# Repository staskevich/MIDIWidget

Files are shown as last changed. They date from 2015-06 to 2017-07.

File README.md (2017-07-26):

MIDIWidget

copyright 2015-2017 John Staskevich

john@codeandcopper.com

This work is licensed under a Creative Commons Attribution 4.0 International License.
http://creativecommons.org/licenses/by/4.0/

HARDWARE:

Eagle 6 board and schematic are in the pcb/ folder. There is also a design for a "programming cradle" that mates the test points on the MIDIWidget with a AVR programmer for ISP.

A public CircuitHub project is available for on-demand manufacturing:
https://circuithub.com/projects/CodeandCopper1/MIDIWidget

FIRMWARE:

See README.txt in Firmware/ and Bootloader/ folders.

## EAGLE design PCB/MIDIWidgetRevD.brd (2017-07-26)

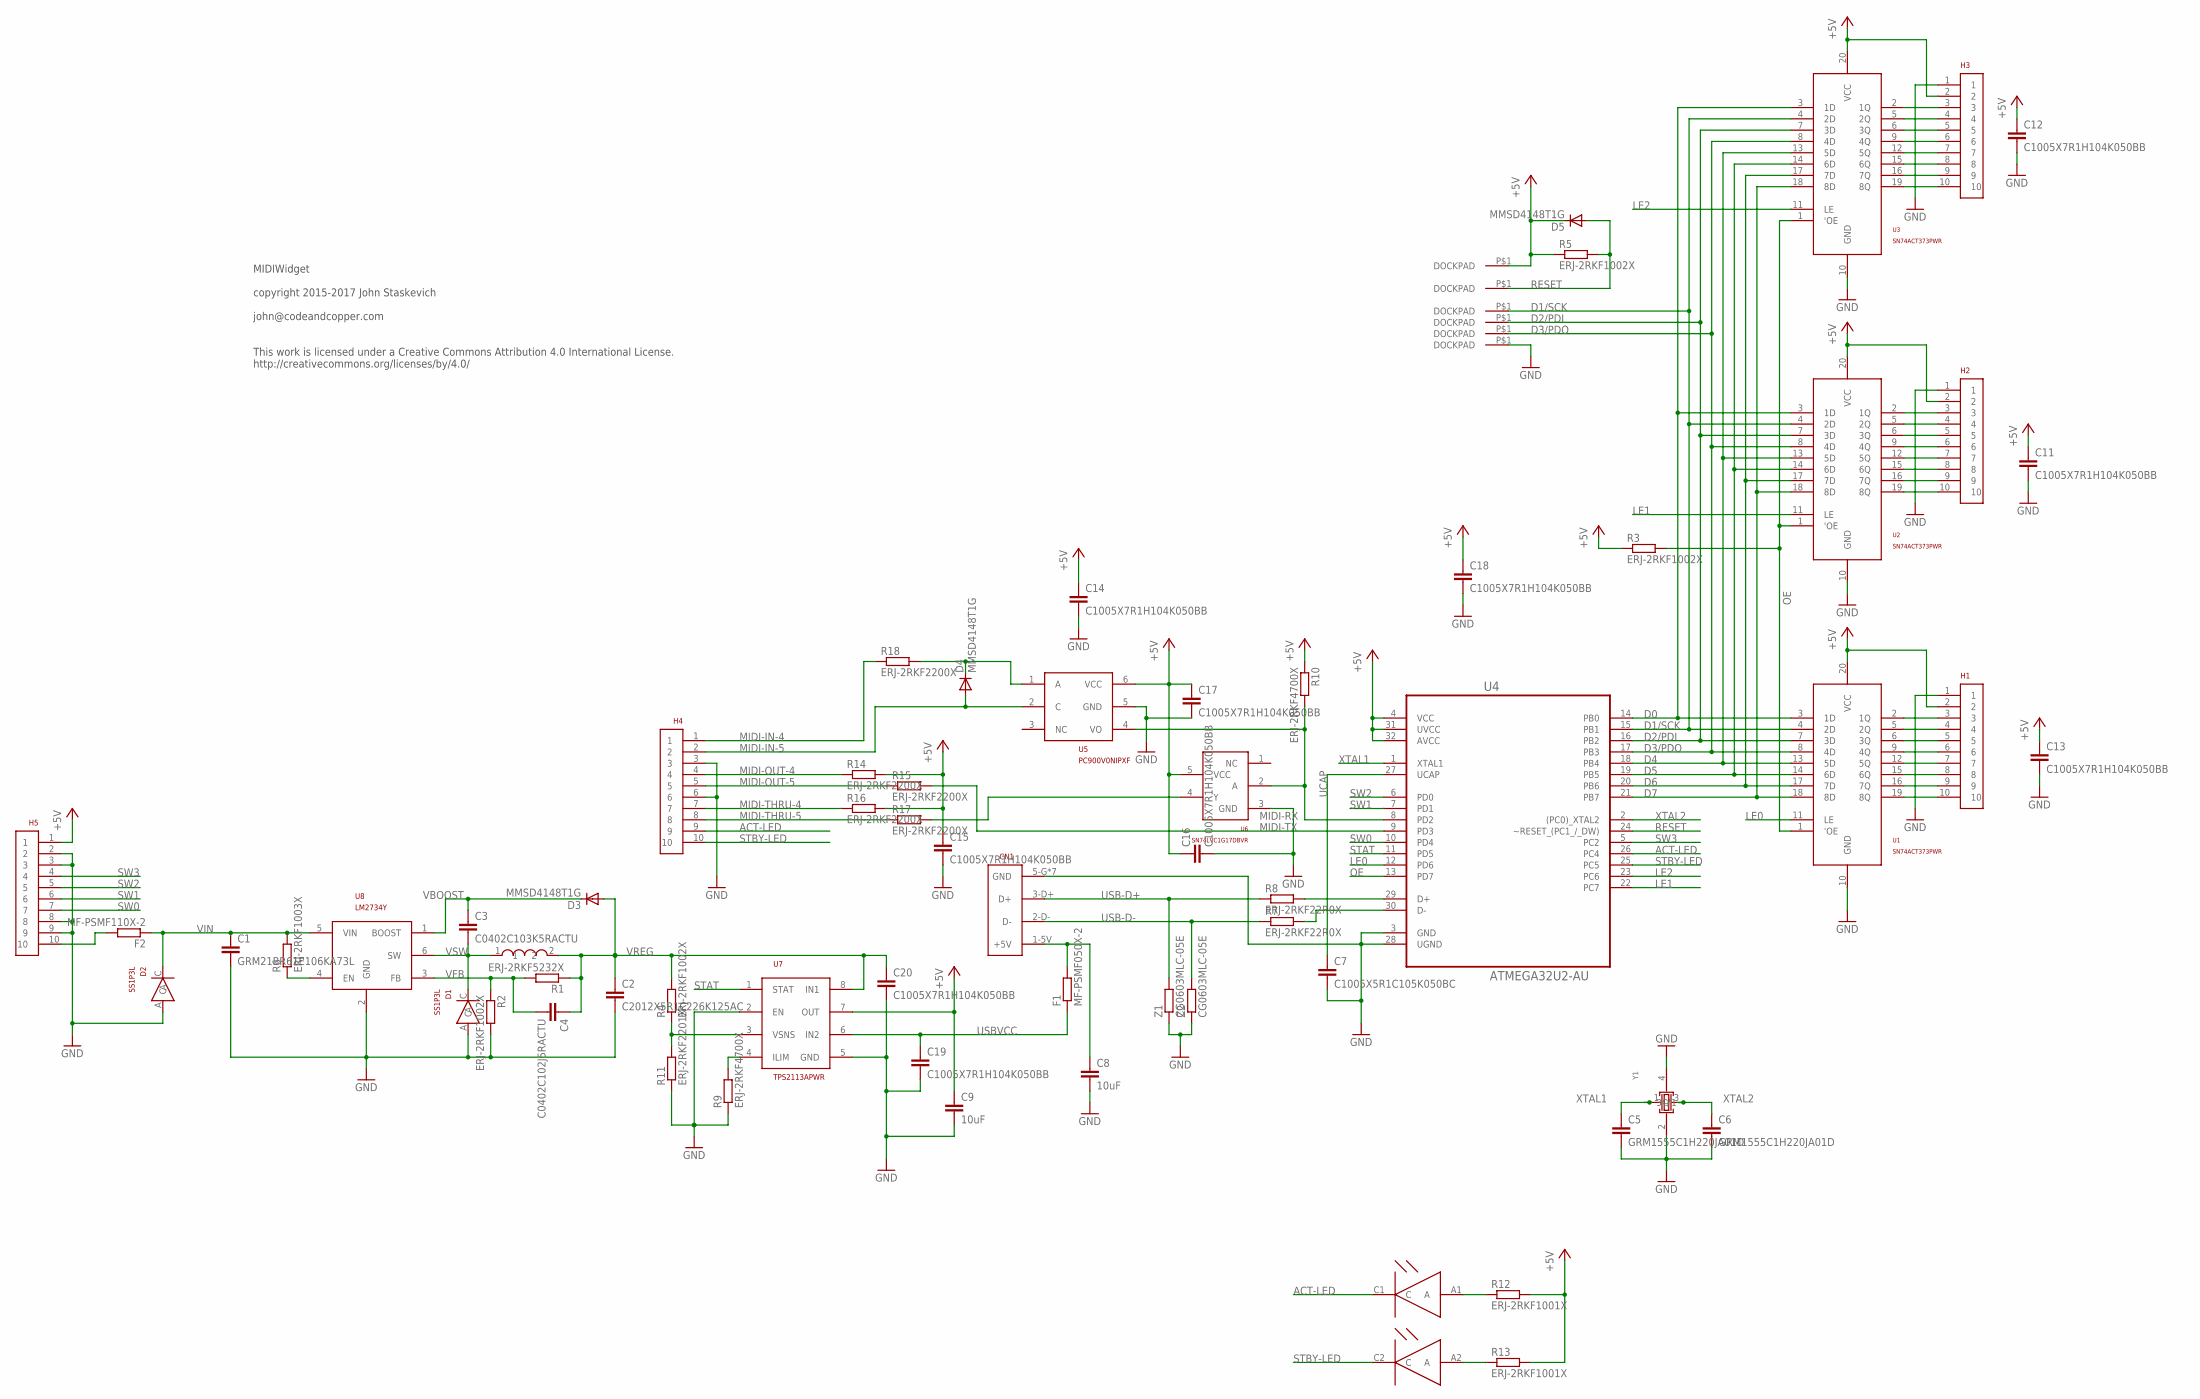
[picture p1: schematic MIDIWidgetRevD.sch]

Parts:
C1: GRM21BR61E106KA73L; C0805
C2: C2012X5R1C226K125AC; C0805
C3: C0402C103K5RACTU; C0402
C4: C0402C102J5RACTU; C0402
C5, C6: GRM1555C1H220JA01D; C0402
C7: C1005X5R1C105K050BC; C0402
C8, C9: 10uF; C0805
C11, C12, C13, C14, C15, C16, C17, C18, C19, C20: C1005X7R1H104K050BB; C0402
CN1: 10118192-0001LF; USB-MICRO-B
D1, D2: SS1P3L; DO-220AA(SMP)
D3, D4, D5: MMSD4148T1G; SOD123
DOCK-GND: DOCKPAD; DOCKPAD-ROUND-2.0MM
DOCK-PDI: DOCKPAD; DOCKPAD-ROUND-2.0MM
DOCK-PDO: DOCKPAD; DOCKPAD-ROUND-2.0MM
DOCK-RESET: DOCKPAD; DOCKPAD-ROUND-2.0MM
DOCK-SCK: DOCKPAD; DOCKPAD-ROUND-2.0MM
DOCK-VCC: DOCKPAD; DOCKPAD-ROUND-2.0MM
F1: MF-PSMF050X-2; R0805
F2: MF-PSMF110X-2; R0805
H1, H2, H3, H4, H5: TERMINAL-BLOCK-10POS; TB-2-54-10POS
L1: SLF7055T-220M1R7-3PF; SLF7055
LED: HSMF-C155; LUMEX-1210-DUAL-LED
R1: ERJ-2RKF5232X; R0402
R2, R3, R4, R5: ERJ-2RKF1002X; R0402
R6: ERJ-2RKF1003X; R0402
R7, R8: ERJ-2RKF22R0X; R0402
R9, R10: ERJ-2RKF4700X; R0402
R11: ERJ-2RKF2201X; R0402
R12, R13: ERJ-2RKF1001X; R0402
R14, R15, R16, R17, R18: ERJ-2RKF2200X; R0402
U1, U2, U3: SN74ACT373PWR; TSSOP-20
U4: ATMEGA32U2-AU; QFP80P900X900X120-32N
U5: PC900V0NIPXF; SMT-6
U6: SN74LVC1G17DBVR; SOT23-5-GOOD
U7: TPS2113APWR; TSSOP-8-NAKED
U8: LM2734Y; TSOT-6
Y1: 403C35E16M00000; CRYSTAL-32-25MM
Z1, Z2: CG0603MLC-05E; R0603

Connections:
+5V: C9.1, C11.1, C12.1, C13.1, C14.1, C15.1, C16.1, C17.1, C18.1, D5.C, DOCK-VCC.P$1, H1.2, H2.2, H3.2, H5.1, R3.1, R5.1, R10.1, R12.2, R13.2, R14.2, R16.2, U1.20 (VCC), U2.20 (VCC), U3.20 (VCC), U4.4 (VCC), U4.31 (UVCC), U4.32 (AVCC), U5.6 (VCC), U6.5 (VCC), U7.7 (OUT)
ACT-LED: H4.9, LED.C1 (C), U4.26 (PC4)
D0: U1.3 (1D), U2.3 (1D), U3.3 (1D), U4.14 (PB0)
D1/SCK: DOCK-SCK.P$1, U1.4 (2D), U2.4 (2D), U3.4 (2D), U4.15 (PB1)
D2/PDI: DOCK-PDI.P$1, U1.7 (3D), U2.7 (3D), U3.7 (3D), U4.16 (PB2)
D3/PDO: DOCK-PDO.P$1, U1.8 (4D), U2.8 (4D), U3.8 (4D), U4.17 (PB3)
D4: U1.13 (5D), U2.13 (5D), U3.13 (5D), U4.18 (PB4)
D5: U1.14 (6D), U2.14 (6D), U3.14 (6D), U4.19 (PB5)
D6: U1.17 (7D), U2.17 (7D), U3.17 (7D), U4.20 (PB6)
D7: U1.18 (8D), U2.18 (8D), U3.18 (8D), U4.21 (PB7)
EN: R6.1, U8.4 (EN)
GND: C1.2, C2.2, C5.2, C6.2, C7.2, C8.2, C9.2, C11.2, C12.2, C13.2, C14.2, C15.2, C16.2, C17.2, C18.2, C19.2, C20.2, CN1.5-G (GND), CN1.P$1 (GND), CN1.P$2 (GND), CN1.P$3 (GND), CN1.P$4 (GND), CN1.P$10 (GND), CN1.P$11 (GND), D1.A, D2.A, DOCK-GND.P$1, H1.1, H2.1, H3.1, H4.3, H4.6, H5.2, H5.3, H5.8, H5.9, R2.2, R9.1, R11.1, U1.10 (GND), U2.10 (GND), U3.10 (GND), U4.3 (GND), U4.28 (UGND), U5.5 (GND), U6.3 (GND), U7.2 (EN), U7.5 (GND), U8.2 (GND), Y1.2, Y1.4, Z1.1, Z2.1
ILIM: R9.2, U7.4 (ILIM)
LE0: U1.11 (LE), U4.12 (PD6)
LE1: U2.11 (LE), U4.22 (PC7)
LE2: U3.11 (LE), U4.23 (PC6)
MIDI-IN-4: H4.1, R18.1
MIDI-IN-5: D4.A, H4.2, U5.2 (C)
MIDI-OUT-4: H4.4, R14.1
MIDI-OUT-5: H4.5, R15.1
MIDI-RX: R10.2, U4.8 (PD2), U5.4 (VO), U6.2 (A)
MIDI-THRU-4: H4.7, R16.1
MIDI-THRU-5: H4.8, R17.1
MIDI-TX: R15.2, U4.9 (PD3)
unnamed: H1.10, U1.19 (8Q)
unnamed: H1.9, U1.16 (7Q)
unnamed: H1.8, U1.15 (6Q)
unnamed: H1.7, U1.12 (5Q)
unnamed: H1.6, U1.9 (4Q)
unnamed: H1.5, U1.6 (3Q)
unnamed: H1.4, U1.5 (2Q)
unnamed: H1.3, U1.2 (1Q)
unnamed: H2.3, U2.2 (1Q)
unnamed: H2.4, U2.5 (2Q)
unnamed: H2.5, U2.6 (3Q)
unnamed: H2.6, U2.9 (4Q)
unnamed: H2.7, U2.12 (5Q)
unnamed: H2.8, U2.15 (6Q)
unnamed: H2.9, U2.16 (7Q)
unnamed: H2.10, U2.19 (8Q)
unnamed: H3.9, U3.16 (7Q)
unnamed: H3.10, U3.19 (8Q)
unnamed: H3.8, U3.15 (6Q)
unnamed: H3.7, U3.12 (5Q)
unnamed: H3.6, U3.9 (4Q)
unnamed: H3.5, U3.6 (3Q)
unnamed: H3.4, U3.5 (2Q)
unnamed: H3.3, U3.2 (1Q)
unnamed: D4.C, R18.2, U5.1 (A)
unnamed: LED.A1 (A), R12.1
unnamed: LED.A2 (A), R13.1
unnamed: F2.2, H5.10
unnamed: C8.1, CN1.1-5V (+5V), F1.2
unnamed: R17.2, U6.4 (Y)
OE: R3.2, U1.1 ('OE), U2.1 ('OE), U3.1 ('OE), U4.13 (PD7)
RESET: D5.A, DOCK-RESET.P$1, R5.2, U4.24 (~RESET_(PC1_/_DW))
STAT: U4.11 (PD5), U7.1 (STAT)
STBY-LED: H4.10, LED.C2 (C), U4.25 (PC5)
SW0: H5.7, U4.10 (PD4)
SW1: H5.6, U4.7 (PD1)
SW2: H5.5, U4.6 (PD0)
SW3: H5.4, U4.5 (PC2)
UCAP: C7.1, U4.27 (UCAP)
USB-D+: CN1.3-D+ (D+), R8.1, Z1.2
USB-D+R: R8.2, U4.29 (D+)
USB-D-: CN1.2-D- (D-), R7.1, Z2.2
USB-D-R: R7.2, U4.30 (D-)
USBVCC: C19.1, F1.1, U7.6 (IN2)
VBOOST: C3.1, D3.C, U8.1 (BOOST)
VFB: C4.2, R1.2, R2.1, U8.3 (FB)
VIN: C1.1, D2.C, F2.1, R6.2, U8.5 (VIN)
VREG: C2.1, C4.1, C20.1, D3.A, L1.2, R1.1, R4.2, U7.8 (IN1)
VSNS: R4.1, R11.2, U7.3 (VSNS)
VSW: C3.2, D1.C, L1.1, U8.6 (SW)
XTAL1: C5.1, U4.1 (XTAL1), Y1.1
XTAL2: C6.1, U4.2 ((PC0)_XTAL2), Y1.3

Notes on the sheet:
MIDIWidget copyright 2015-2017 John Staskevich john@codeandcopper.com This work is licensed under a Creative Commons Attribution 4.0 International License. http://creativecommons.org/licenses/by/4.0/

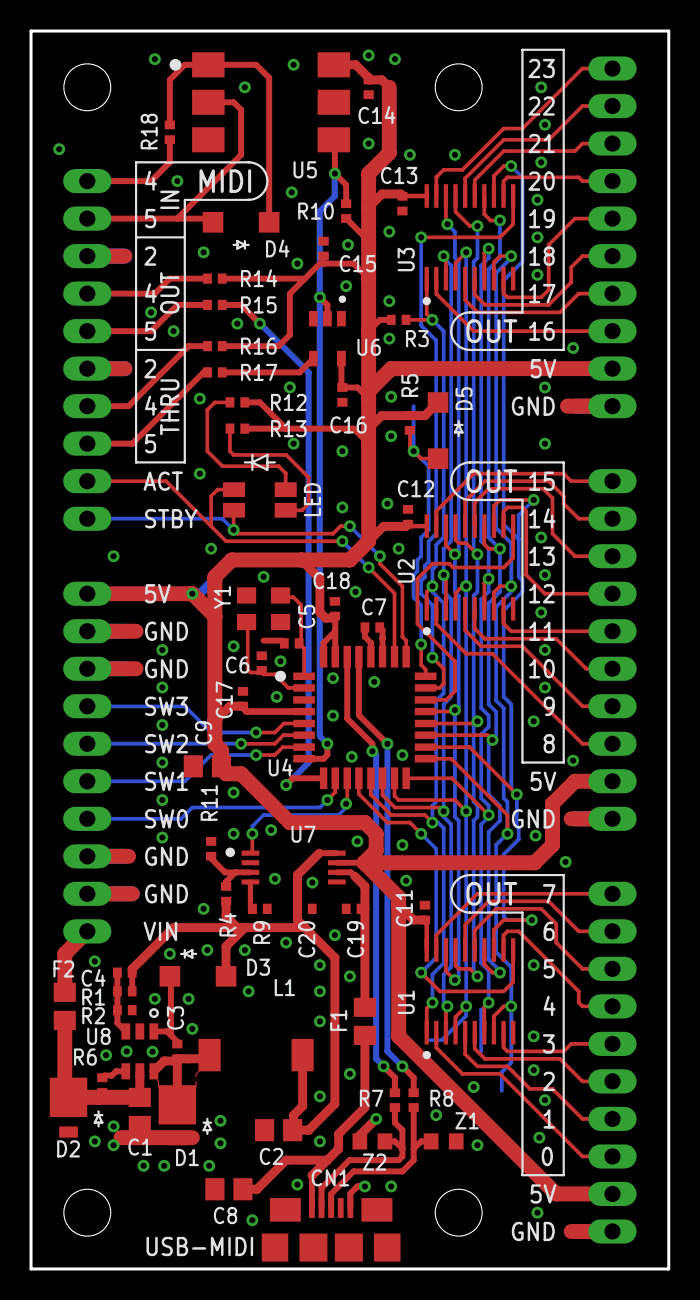
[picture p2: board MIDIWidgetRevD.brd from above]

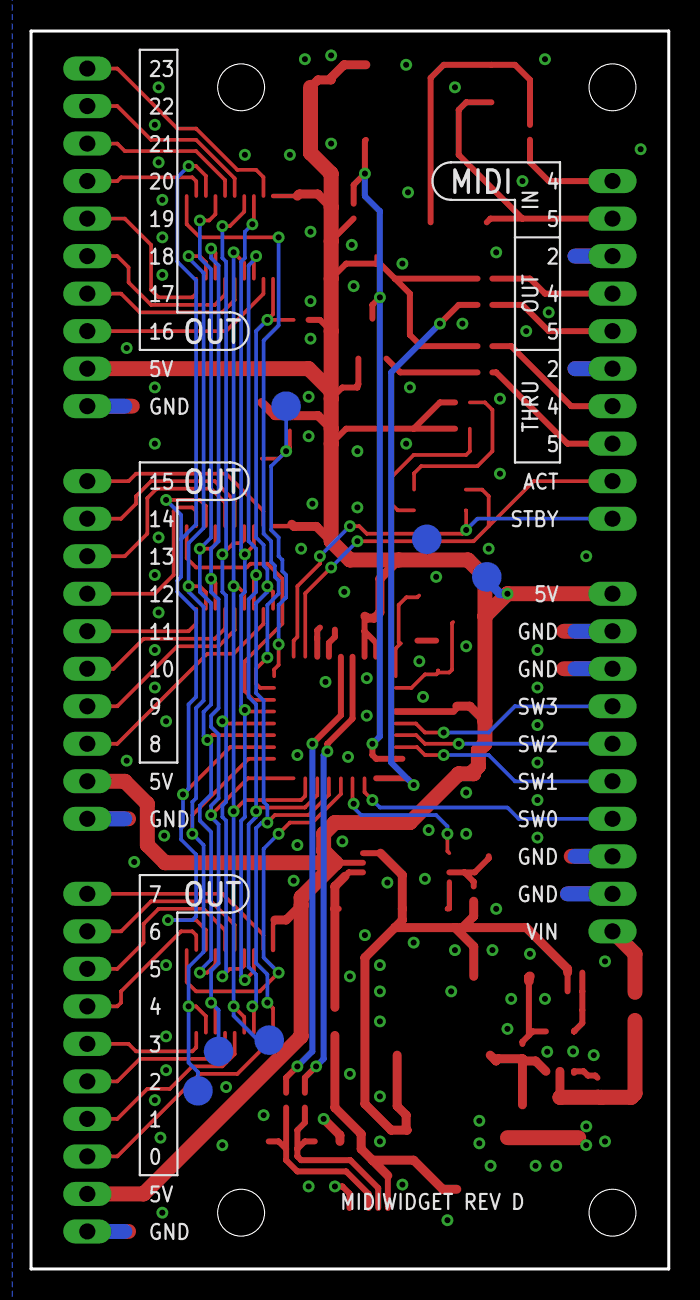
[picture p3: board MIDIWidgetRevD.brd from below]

Board: 2 copper layers, 43.2 x 83.8 mm, 69 parts (6 on the bottom side), 76 nets.

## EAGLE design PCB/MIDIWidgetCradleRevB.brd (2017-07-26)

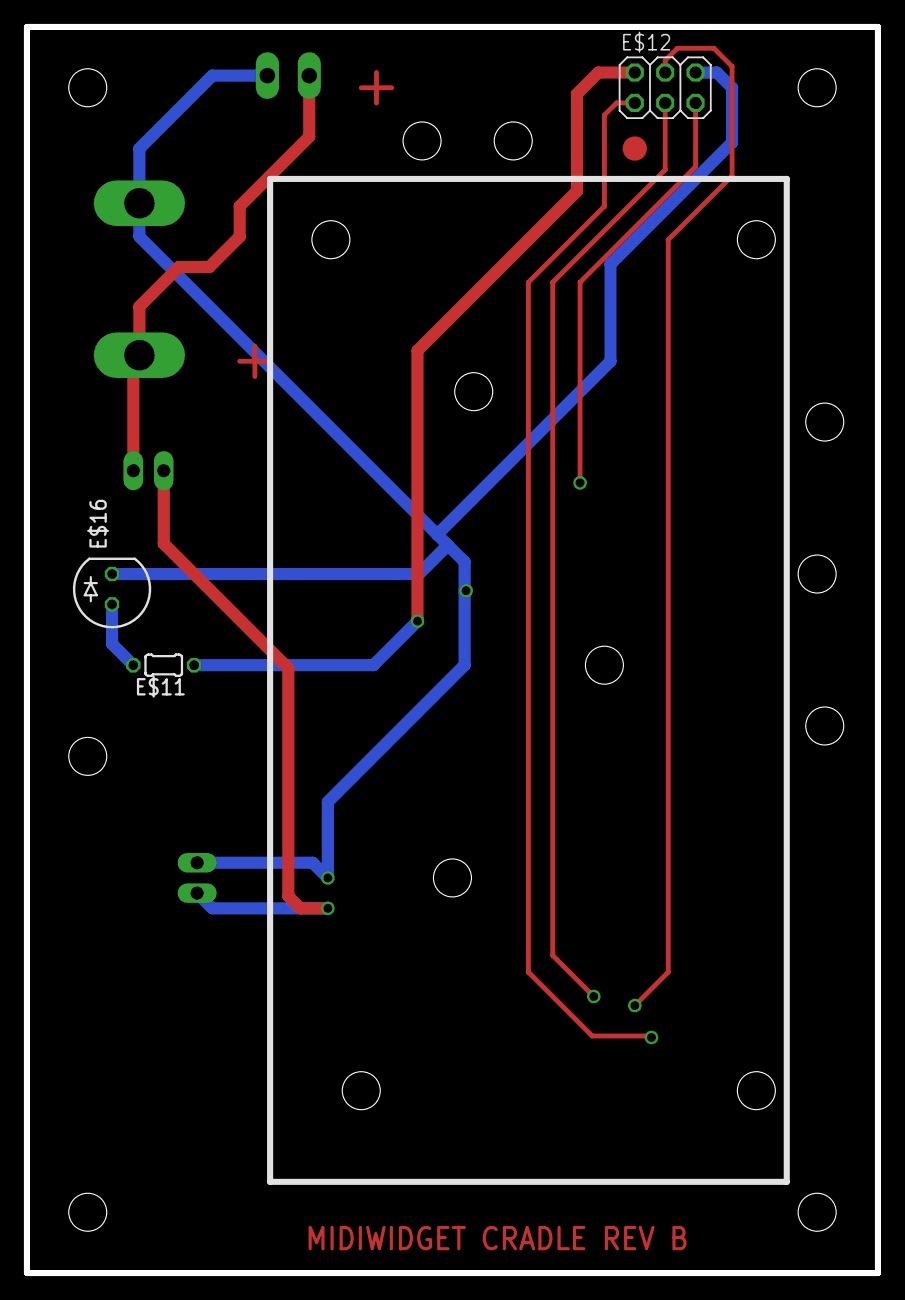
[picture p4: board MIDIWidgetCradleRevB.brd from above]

Board: 2 copper layers, 71.1 x 104.1 mm, 15 parts (0 on the bottom side), 9 nets.

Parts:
E$1: STUD9V
E$2: TERMINAL-BLOCK-3-5-2POS
E$3, E$4, E$5, E$6, E$7, E$8, E$9, E$10: SPRING-CONTACT-025
E$11: 0204/5
E$12: 2X03
E$13, E$15: TB-2-54-2POS
E$16: LED5MM

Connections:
GND: E$1.P$2, E$2.P$1, E$4.P$1, E$9.P$1, E$12.6, E$13.P$3, E$16.K
ICSPCLK: E$5.P$1, E$12.3
ICSPDAT: E$6.P$1, E$12.1
S$2: E$3.P$1, E$12.5
S$8: E$11.2, E$16.A
VDD: E$8.P$1, E$11.1, E$12.2
VIN: E$1.P$1, E$2.P$2, E$15.P$1
VINRECT: E$10.P$1, E$13.P$1, E$15.P$3
VPP: E$7.P$1, E$12.4

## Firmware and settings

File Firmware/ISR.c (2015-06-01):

/*
 * MIDIWidget
 * www.midiwidget.com
 * copyright John Staskevich, 2015
 * john@codeandcopper.com
 *
 * This work is licensed under a Creative Commons Attribution 4.0 International License.
 * http://creativecommons.org/licenses/by/4.0/
 *
 * ISR.c
 *
 * Interrupt service routines.
 */ 

#include "MIDIWidget.h"

ISR(TIMER0_OVF_vect)
{
// Easy way to observe timing of interrupt
//    STBYToggle();
	BLINK_COUNTER--;
    PWM_COUNTER = (PWM_COUNTER + 1) & 0b01111111;
	if (BLINK_COUNTER == 0)
	{
		ACTOff();
	}
    if (DURATION[0] != 0)
    {
        DURATION[0]--;
        if (DURATION[0] == 0)
        {
            LATCH[0] &= 0b11111110;
            PWM[0] = 0xFF;
        }
    }
    if (PWM[0] != 0xFF)
    {
        if (PWM[0] <= PWM_COUNTER)
        {
            LATCH[0] &= 0b11111110;
        }
        else
        {
            LATCH[0] |= 0b00000001;
        }
    }

    if (DURATION[1] != 0)
    {
        DURATION[1]--;
        if (DURATION[1] == 0)
        {
            LATCH[0] &= 0b11111101;
            PWM[1] = 0xFF;
        }
    }
    if (PWM[1] != 0xFF)
    {
        if (PWM[1] <= PWM_COUNTER)
        {
            LATCH[0] &= 0b11111101;
        }
        else
        {
            LATCH[0] |= 0b00000010;
        }
    }

    if (DURATION[2] != 0)
    {
        DURATION[2]--;
        if (DURATION[2] == 0)
        {
            LATCH[0] &= 0b11111011;
            PWM[2] = 0xFF;
        }
    }
    if (PWM[2] != 0xFF)
    {
        if (PWM[2] <= PWM_COUNTER)
        {
            LATCH[0] &= 0b11111011;
        }
        else
        {
            LATCH[0] |= 0b00000100;
        }
    }

    if (DURATION[3] != 0)
    {
        DURATION[3]--;
        if (DURATION[3] == 0)
        {
            LATCH[0] &= 0b11110111;
            PWM[3] = 0xFF;
        }
    }
    if (PWM[3] != 0xFF)
    {
        if (PWM[3] <= PWM_COUNTER)
        {
            LATCH[0] &= 0b11110111;
        }
        else
        {
            LATCH[0] |= 0b00001000;
        }
    }

    if (DURATION[4] != 0)
    {
        DURATION[4]--;
        if (DURATION[4] == 0)
        {
            LATCH[0] &= 0b11101111;
            PWM[4] = 0xFF;
        }
    }
    if (PWM[4] != 0xFF)
    {
        if (PWM[4] <= PWM_COUNTER)
        {
            LATCH[0] &= 0b11101111;
        }
        else
        {
            LATCH[0] |= 0b00010000;
        }
    }

    if (DURATION[5] != 0)
    {
        DURATION[5]--;
        if (DURATION[5] == 0)
        {
            LATCH[0] &= 0b11011111;
            PWM[5] = 0xFF;
        }
    }
    if (PWM[5] != 0xFF)
    {
        if (PWM[5] <= PWM_COUNTER)
        {
            LATCH[0] &= 0b11011111;
        }
        else
        {
            LATCH[0] |= 0b00100000;
        }
    }

    if (DURATION[6] != 0)
    {
        DURATION[6]--;
        if (DURATION[6] == 0)
        {
            LATCH[0] &= 0b10111111;
            PWM[6] = 0xFF;
        }
    }
    if (PWM[6] != 0xFF)
    {
        if (PWM[6] <= PWM_COUNTER)
        {
            LATCH[0] &= 0b10111111;
        }
        else
        {
            LATCH[0] |= 0b01000000;
        }
    }

    if (DURATION[7] != 0)
    {
        DURATION[7]--;
        if (DURATION[7] == 0)
        {
            LATCH[0] &= 0b01111111;
            PWM[7] = 0xFF;
        }
    }
    if (PWM[7] != 0xFF)
    {
        if (PWM[7] <= PWM_COUNTER)
        {
            LATCH[0] &= 0b01111111;
        }
        else
        {
            LATCH[0] |= 0b10000000;
        }
    }

    if (DURATION[8] != 0)
    {
        DURATION[8]--;
        if (DURATION[8] == 0)
        {
            LATCH[1] &= 0b11111110;
        }
    }
    if (PWM[8] != 0xFF)
    {
        if (PWM[8] <= PWM_COUNTER)
        {
            LATCH[1] &= 0b11111110;
        }
        else
        {
            LATCH[1] |= 0b00000001;
        }
    }

    if (DURATION[9] != 0)
    {
        DURATION[9]--;
        if (DURATION[9] == 0)
        {
            LATCH[1] &= 0b11111101;
        }
    }
    if (PWM[9] != 0xFF)
    {
        if (PWM[9] <= PWM_COUNTER)
        {
            LATCH[1] &= 0b11111101;
        }
        else
        {
            LATCH[1] |= 0b00000010;
        }
    }

    if (DURATION[10] != 0)
    {
        DURATION[10]--;
        if (DURATION[10] == 0)
        {
            LATCH[1] &= 0b11111011;
        }
    }
    if (PWM[10] != 0xFF)
    {
        if (PWM[10] <= PWM_COUNTER)
        {
            LATCH[1] &= 0b11111011;
        }
        else
        {
            LATCH[1] |= 0b00000100;
        }
    }

    if (DURATION[11] != 0)
    {
        DURATION[11]--;
        if (DURATION[11] == 0)
        {
            LATCH[1] &= 0b11110111;
        }
    }
    if (PWM[11] != 0xFF)
    {
        if (PWM[11] <= PWM_COUNTER)
        {
            LATCH[1] &= 0b11110111;
        }
        else
        {
            LATCH[1] |= 0b00001000;
        }
    }

    if (DURATION[12] != 0)
    {
        DURATION[12]--;
        if (DURATION[12] == 0)
        {
            LATCH[1] &= 0b11101111;
        }
    }
    if (PWM[12] != 0xFF)
    {
        if (PWM[12] <= PWM_COUNTER)
        {
            LATCH[1] &= 0b11101111;
        }
        else
        {
            LATCH[1] |= 0b00010000;
        }
    }

    if (DURATION[13] != 0)
    {
        DURATION[13]--;
        if (DURATION[13] == 0)
        {
            LATCH[1] &= 0b11011111;
        }
    }
    if (PWM[13] != 0xFF)
    {
        if (PWM[13] <= PWM_COUNTER)
        {
            LATCH[1] &= 0b11011111;
        }
        else
        {
            LATCH[1] |= 0b00100000;
        }
    }

    if (DURATION[14] != 0)
    {
        DURATION[14]--;
        if (DURATION[14] == 0)
        {
            LATCH[1] &= 0b10111111;
        }
    }
    if (PWM[14] != 0xFF)
    {
        if (PWM[14] <= PWM_COUNTER)
        {
            LATCH[1] &= 0b10111111;
        }
        else
        {
            LATCH[1] |= 0b01000000;
        }
    }

    if (DURATION[15] != 0)
    {
        DURATION[15]--;
        if (DURATION[15] == 0)
        {
            LATCH[1] &= 0b01111111;
        }
    }
    if (PWM[15] != 0xFF)
    {
        if (PWM[15] <= PWM_COUNTER)
        {
            LATCH[1] &= 0b01111111;
        }
        else
        {
            LATCH[1] |= 0b10000000;
        }
    }

    if (DURATION[16] != 0)
    {
        DURATION[16]--;
        if (DURATION[16] == 0)
        {
            LATCH[2] &= 0b11111110;
        }
    }
    if (PWM[16] != 0xFF)
    {
        if (PWM[16] <= PWM_COUNTER)
        {
            LATCH[2] &= 0b11111110;
        }
        else
        {
            LATCH[2] |= 0b00000001;
        }
    }

    if (DURATION[17] != 0)
    {
        DURATION[17]--;
        if (DURATION[17] == 0)
        {
            LATCH[2] &= 0b11111101;
        }
    }
    if (PWM[17] != 0xFF)
    {
        if (PWM[17] <= PWM_COUNTER)
        {
            LATCH[2] &= 0b11111101;
        }
        else
        {
            LATCH[2] |= 0b00000010;
        }
    }
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

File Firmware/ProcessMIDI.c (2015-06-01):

/*
 * MIDIWidget
 * www.midiwidget.com
 * copyright John Staskevich, 2015
 * john@codeandcopper.com
 *
 * This work is licensed under a Creative Commons Attribution 4.0 International License.
 * http://creativecommons.org/licenses/by/4.0/
 *
 * ProcessMIDI.c
 *
 * Parse MIDI data streams and handle MIDI events.
 */ 

#include "MIDIWidget.h"

uint8_t SERIAL_RX_BUFFER[SERIAL_RX_BUFFER_SIZE];
uint8_t SERIAL_RX_BUFFER_HEAD;
uint8_t SERIAL_RX_BUFFER_TAIL;
uint8_t SERIAL_RX_BUFFER_FILL;
uint8_t SERIAL_TX_BUFFER[SERIAL_TX_BUFFER_SIZE];
uint8_t SERIAL_TX_BUFFER_HEAD;
uint8_t SERIAL_TX_BUFFER_TAIL;
uint8_t SERIAL_TX_BUFFER_FILL;

// Read MIDI bytes from the combined RX/USB queue and:
// 1. echo MIDI byte at serial port (if enabled)
// 2. update output states as necessary.
void ProcessSerialMIDI()
{
    uint8_t MIDI_BYTE;

    // check for empty FIFO
    if (SERIAL_RX_BUFFER_FILL != 0)
    {
        // pull byte from FIFO
        cli();
        MIDI_BYTE = SERIAL_RX_BUFFER[SERIAL_RX_BUFFER_HEAD++];
        SERIAL_RX_BUFFER_HEAD %= SERIAL_RX_BUFFER_SIZE;
        SERIAL_RX_BUFFER_FILL--;
        sei();

        ParseMIDIByte(MIDI_BYTE, STREAM_SERIAL_MIDI);
    }
}

void ParseMIDIByte(uint8_t MIDI_BYTE, uint8_t s)
{
    static uint8_t RUNNING_STATUS[NUM_UNPARSED_STREAMS] = {0x00, 0x00};
    static uint8_t BYTE_COUNT[NUM_UNPARSED_STREAMS] = {0x00, 0x00};
    static uint8_t DATA_0[NUM_UNPARSED_STREAMS] = {0x00, 0x00};
    // status byte or data byte?
    if (MIDI_BYTE & 0b10000000)
    {
        // status byte. handle in 3 categories: system real time, channel-specific, system common.
        if (MIDI_BYTE >= 0xF8)
        {
            ProcessMIDIRealTime(MIDI_BYTE);
            if (! (OPERATION_FLAGS & (1<<DISABLE_SERIAL_MIDI_THRU_FLAG)))
            {
                QueueMIDIEvent(1, MIDI_BYTE, 0, 0);
            }
        }
        else if (MIDI_BYTE < 0xF0)
        {
            // channel-specific status.
            RUNNING_STATUS[s] = MIDI_BYTE;
            BYTE_COUNT[s] = 0;
        }
        else
        {
            // system common.
            RUNNING_STATUS[s] = 0x00;
            BYTE_COUNT[s] = 0;
        }
    } // status byte
    else
    {
        // data byte.
        // is this the first data byte in the message?
        if (BYTE_COUNT[s] == 0)
        {
            // check for program change (single data byte)
            switch (RUNNING_STATUS[s] & 0xF0)
            {
                case 0xC0:
                    ProcessProgramChange(RUNNING_STATUS[s] & 0x0F, MIDI_BYTE);
                    if (! (OPERATION_FLAGS & (1<<DISABLE_SERIAL_MIDI_THRU_FLAG)))
                    {
                        QueueMIDIEvent(2, RUNNING_STATUS[s],MIDI_BYTE,0);
                    }
                    break;
                case 0xD0:
                    ProcessChannelPressure(RUNNING_STATUS[s] & 0x0F, MIDI_BYTE);
                    if (! (OPERATION_FLAGS & (1<<DISABLE_SERIAL_MIDI_THRU_FLAG)))
                    {
                        QueueMIDIEvent(2, RUNNING_STATUS[s],MIDI_BYTE,0);
                    }
                    break;
                default:
                    // store the first data byte and exit.
                    DATA_0[s] = MIDI_BYTE;
                    BYTE_COUNT[s]++;
                    break;
            }
        }
        else // BYTE_COUNT > 0
        {
            // reset bytecount for next message.
            BYTE_COUNT[s] = 0;
            // check for message type and process data.
            switch (RUNNING_STATUS[s] & 0xF0)
            {
                case 0x80:
                    ProcessNoteOff(RUNNING_STATUS[s] & 0x0F, DATA_0[s]);
                    if (! (OPERATION_FLAGS & (1<<DISABLE_SERIAL_MIDI_THRU_FLAG)))
                    {
                        QueueMIDIEvent(3, RUNNING_STATUS[s],DATA_0[s],MIDI_BYTE);
                    }
                    break;
                case 0x90:
                    ProcessNoteOn(RUNNING_STATUS[s] & 0x0F, DATA_0[s], MIDI_BYTE);
                    if (! (OPERATION_FLAGS & (1<<DISABLE_SERIAL_MIDI_THRU_FLAG)))
                    {
                        QueueMIDIEvent(3, RUNNING_STATUS[s],DATA_0[s],MIDI_BYTE);
                    }
                    break;
                case 0xB0:
                    ProcessController(RUNNING_STATUS[s] & 0x0F, DATA_0[s], MIDI_BYTE);
                    if (! (OPERATION_FLAGS & (1<<DISABLE_SERIAL_MIDI_THRU_FLAG)))
                    {
                        QueueMIDIEvent(3, RUNNING_STATUS[s],DATA_0[s],MIDI_BYTE);
                    }
                    break;
                case 0xA0:
                    ProcessAftertouch(RUNNING_STATUS[s] & 0x0F, DATA_0[s], MIDI_BYTE);
                    if (! (OPERATION_FLAGS & (1<<DISABLE_SERIAL_MIDI_THRU_FLAG)))
                    {
                        QueueMIDIEvent(3, RUNNING_STATUS[s],DATA_0[s],MIDI_BYTE);
                    }
                    break;
                case 0xE0:
                    ProcessPitchWheel(RUNNING_STATUS[s] & 0x0F, DATA_0[s], MIDI_BYTE);
                    if (! (OPERATION_FLAGS & (1<<DISABLE_SERIAL_MIDI_THRU_FLAG)))
                    {
                        QueueMIDIEvent(3, RUNNING_STATUS[s],DATA_0[s],MIDI_BYTE);
                    }
                    break;
            }
        }
    } // Data byte
} // ProcessSerialMIDIBytes()
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

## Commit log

2015-06-01 added PCB design
    [MIDIWidgetRevB.brd, MIDIWidgetRevB.sch]
2017-07-26 PCB Rev D
    [MIDIWidgetRevD.brd, MIDIWidgetRevD.sch]
2017-07-26 added cradle PCB for ISP
    [MIDIWidgetCradleRevB.brd]
